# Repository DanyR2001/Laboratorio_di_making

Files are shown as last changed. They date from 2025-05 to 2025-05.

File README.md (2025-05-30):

# 🌀 Deumidificatore Smart DIY

Un deumidificatore intelligente basato su cella Peltier, controllabile via WiFi e Telegram, progettato per essere economico, modulare e open-source.

## 🚀 Panoramica
Progetto nato per risolvere problemi di umidità elevata (>80%) in ambienti domestici, offrendo un'alternativa economica e smart ai deumidificatori commerciali. Combina una cella Peltier con sensori di temperatura/umidità e controllo remoto in un case stampabile in 3D.

## 🔍 Caratteristiche Principali
- **Economico**: Costo totale ~50€ (vs 150-400€ modelli smart)
- **Smart Control**: Interfaccia web locale + Bot Telegram
- **Modulare**: Case stampabile in 3D con design modulare
- **Sostenibile**: Riutilizzo componenti da hardware dismesso
- **Monitoraggio**: Sensori temperatura/umidità in tempo reale
- **Silenzioso**: 37-52 dBA (a seconda della modalità)

## 📦 Componenti Richiesti
| Componente | Quantità | Prezzo Amazon | Prezzo AliExpress |
|---|---|---|---|
| ESP32 | 1 | €6,50 | €2,59 |
| Sensore AHT25 | 2 | €7,99 | €3,64 |
| Modulo Relè | 1 | €1,52 | €2,89 |
| Level Shifter 3.3V-5V | 1 | €1,40 | €0,11 |
| Multiplexer I2C | 1 | €1,60 | €0,42 |
| Alimentatore 12V 5A | 1 | €14,98 | €7,39 |
| DC-DC Step-down | 1 | €2,80 | €1,27 |
| Cella Peltier TEC1-12706| 1 | €4,50 | €2,06 |
| **Totale** | | **€41,29** | **€20,37** |

### 🛠️ Hardware Aggiuntivo
- Scheda Madre AM2 (ASROCK N68-S) per dissipatori: ~€25 su eBay
- Filamento PLA per stampa 3D

## ⚙️ Specifiche Tecniche
| Caratteristica | Valore |
|---|---|
| Capacità deumidificazione  | 0,3-0,4 L/giorno |
| Potenza refrigerante | ~10W |
| Consumo energetico | 24-30W (2,0-2,5A @12V)|
| Temperatura lato freddo | 8-18°C |
| Rumorosità | 37-52 dBA |
| Controllo umidità | 55-65% RH |
| Connettività | WiFi + Telegram Bot |

## 📂 Struttura del Progetto
Laboratorio_di_making/ <br />
├── Stl/           # File 3D per la stampa <br />
│   ├── Part 1.stl <br />
│   ├── Part 2.stl <br />
│   ├── Part 3.stl <br />
│   └── Part 4.stl <br />
├── Codice/        # Codice sorgente <br />
│   └── Main/ <br />
│       ├── main.ino <br />
│       └── exampleConfig.h <br />
├── Data/                # Dati ambientali campionati dai test <br />
│   ├── Umidità/ <br />  # Dati e codice per il test dell'umidità
│   └── Rumore/ <br />   # Dati fonometrice
├── Circuito/            # Schemi elettrici <br />
├── Documentazione/      # Relazione progetto <br />
└── README.md<br />
## ⚡ Setup e Installazione
### 1. Preparazione Hardware
- Stampa 3D: Stampa tutti i componenti del case usando PLA/PETG
- Assemblaggio: Monta i dissipatori dalla scheda madre AM2 sulla cella Peltier
- Cablaggio: Segui lo schema elettrico fornito
- Montaggio: Assembla tutti i componenti nel case stampato

### 2. Setup Software
1. Installa Arduino IDE e le librerie necessarie
2. Carica il firmware sull'ESP32

### 3. Configurazione Telegram BotCerca @BotFather su Telegram
1. Crea un nuovo bot con /newbot
2. Ottieni token e chat ID
3. Inserisci i dati in config.h

### 4. Accesso Web Interface 
- URL locale: http://esp32.local/
- API sensori: http://esp32.local/localSensors

## 📊 Prestazioni e Test
### Test di Collaudo
- Riduzione umidità: ~10% in 10 ore
- Rimozione vapore: ~150ml/50m³
- Temperatura operativa: Lato freddo 8-18°C, lato caldo ~50°C

### 🔈 Profilo Acustico

| Modalità | Livello Sonoro  |
|---|---|
| Sleep | 37,7 dBA |
| Min | 40 dBA |
| Med | 43 dBA |
| Max | 52 dBA |	
	
### ⚡ Efficienza Energetica
- Punto ottimale: 2,0-2,5A @ 12V
- COP: 0,7-0,8 nella zona ottimale
- Potenza frigorifera: 7-12W

## 🖥️ Utilizzo
### Web Interface
- Controllo ON/OFF del deumidificatore
- Monitoraggio temperature lato caldo/freddo
- Regolazione velocità ventola
- Visualizzazione dati sensori

### 🤖 Telegram Bot
- Stessi controlli dell'interfaccia web
- Controllo accesso tramite ID Telegram

## 🛠️ Personalizzazione
### Hardware
- Dissipatori maggiori per prestazioni superiori
- Doppia cella Peltier (configurazione cascata/parallela)
- Sistema di drenaggio per uso continuo

## Software
- Logging su SD per storico dati
- Integrazione cloud (dashboard online)
- App mobile dedicata
- Algoritmi ML per ottimizzazione automatica

## 🚀 Sviluppi Futuri
- Dashboard avanzata con grafici storici
- Integrazione domotica (Home Assistant, Alexa)
- AI optimization per cicli automatici
- App mobile nativa
- Cloud storage per i dati
- Notifiche push personalizzate

## 🤝 Contribuire
Contributi benvenuti! Processo suggerito:
1. Fork del repository
2. Crea un branch per la tua feature (git checkout -b feature/AmazingFeature)
3. Commit delle modifiche (git commit -m 'Add some AmazingFeature')
4. Push sul branch (git push origin feature/AmazingFeature)
5. Apri una Pull Request

### Aree di contributo
- Bug fix e ottimizzazioni
- Nuove funzionalità
- Miglioramenti documentazione
- Modifiche design case
- Test in condizioni diverse

## 📜 Licenza
Distribuito con licenza MIT. Vedi LICENSE per dettagli.

## ❓ Supporto
- Issues: Usa la sezione Issues di GitHub
- Discussioni: Partecipa alle Discussions
- Contatto diretto: [danielerusso_@hotmail.it]

## Disclaimer
Questo progetto è fornito "as-is" per scopi educativi e di prototipazione. Utilizzare con cautela rispettando le norme di sicurezza elettrica.

# ⭐ Se questo progetto ti è stato utile, lascia una stella su GitHub!

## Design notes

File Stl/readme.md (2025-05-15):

# Printer Setting
Ho stampato questi modelli con delle impostazioni classiche, utilizzando del PETG
- Infill 15%
- Altezza layer: 0.2 mm
- temperatura di stampa 240°

Nei file:
- Part 2
- Part 3
Sono necessari dei supporti per la stampa

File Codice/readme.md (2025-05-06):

# Some info
Qui è riportato un file exampleConfig.h che dovrai compilare per far funzionare l'esp32!!

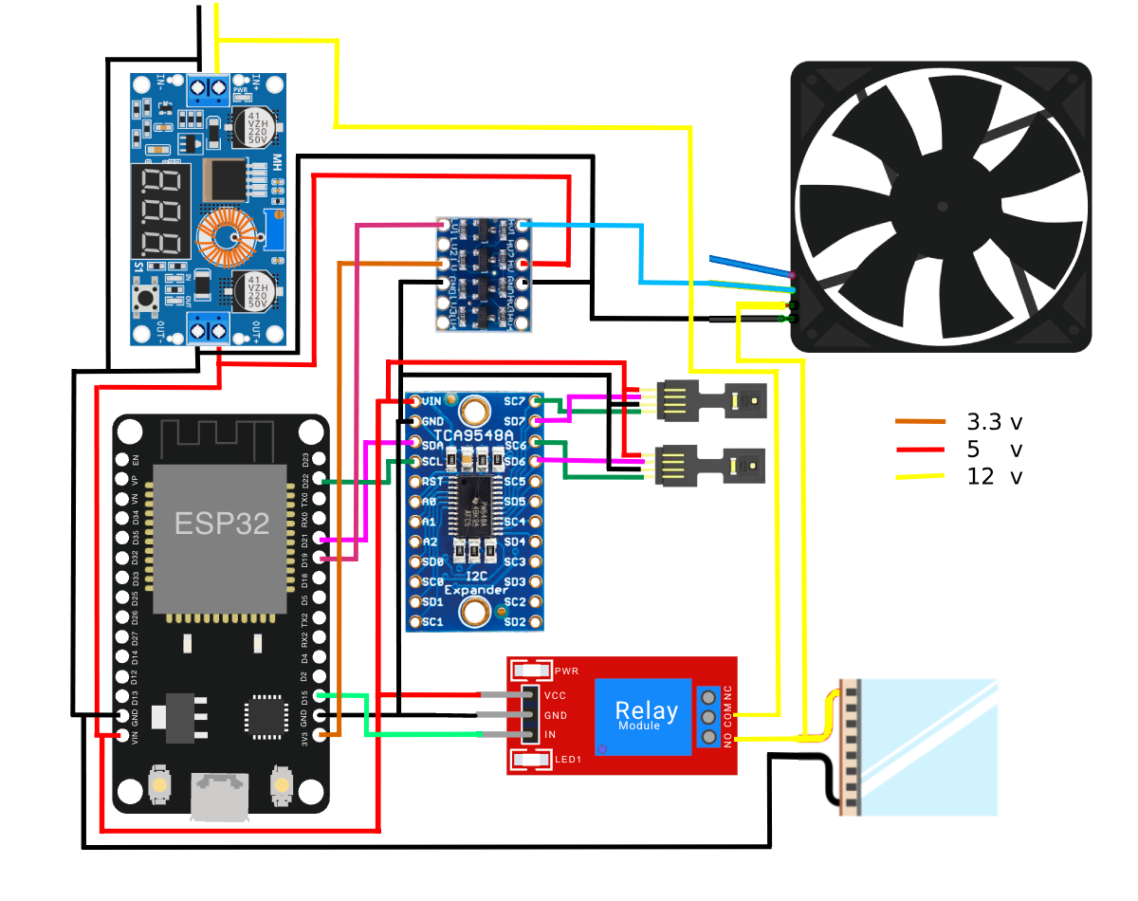
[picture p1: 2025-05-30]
Circuito/schema collegamenti.png

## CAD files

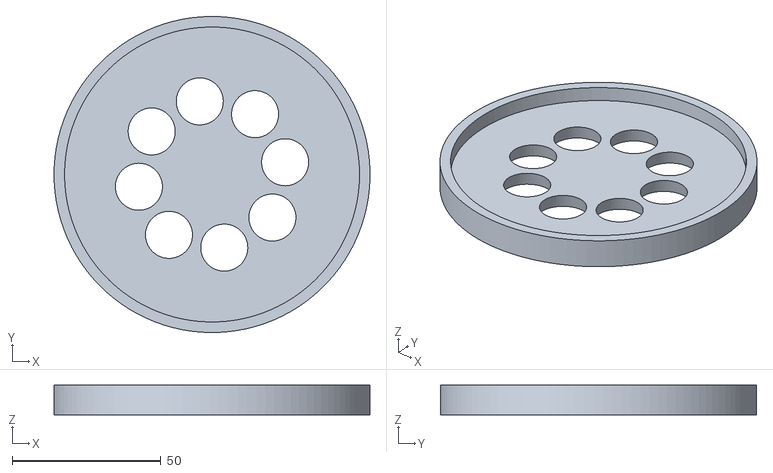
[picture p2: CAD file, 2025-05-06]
Stl/Part 1.stl
106.1 x 106.1 x 10.0

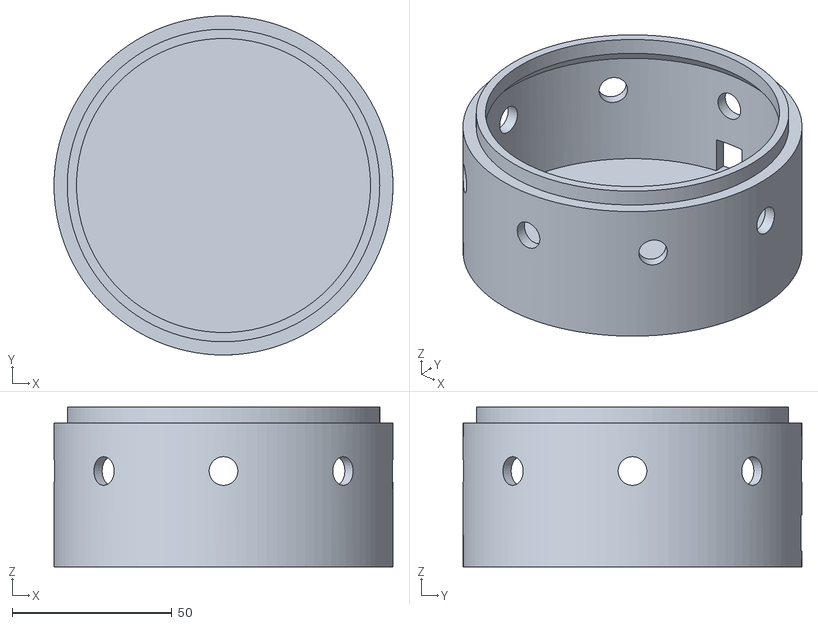
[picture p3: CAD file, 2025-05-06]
Stl/Part 4.stl
106.1 x 106.1 x 50.0

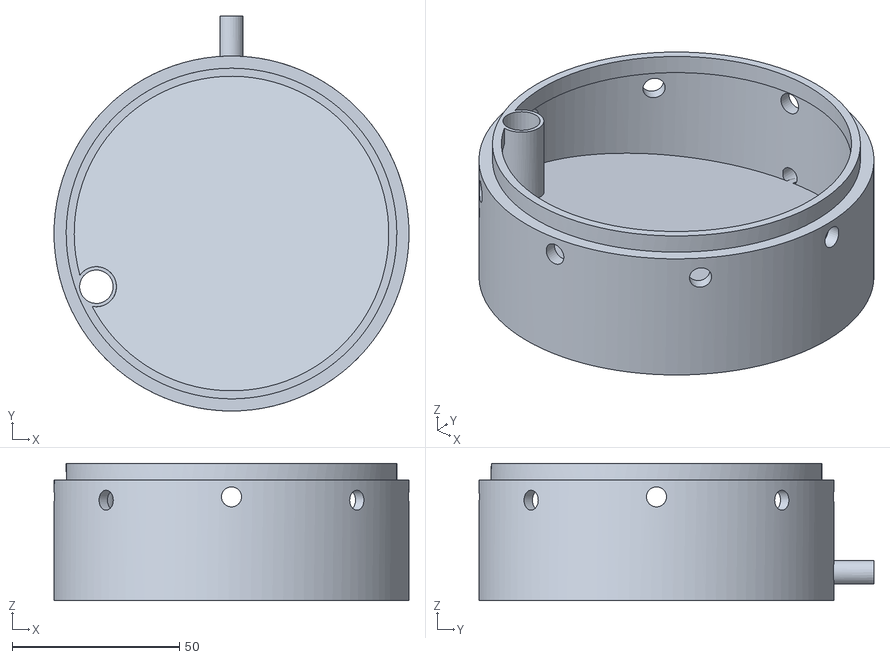
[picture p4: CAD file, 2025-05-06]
Stl/Part 3.stl
106.1 x 118.0 x 41.0

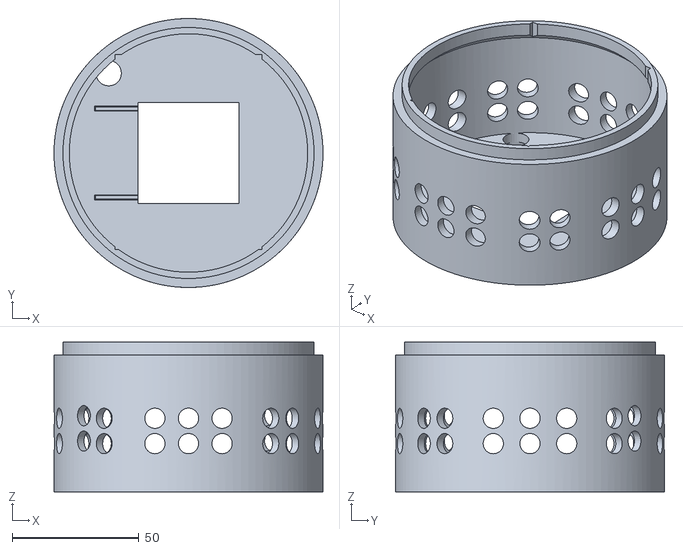
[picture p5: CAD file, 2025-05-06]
Stl/Part 2.stl
106.1 x 106.1 x 59.0

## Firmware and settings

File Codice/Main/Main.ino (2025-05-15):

#include <HTTPClient.h>
#include <WiFi.h>
#include <WebServer.h>
#include <AHTxx.h>
#include <Wire.h>
#include <WiFiClientSecure.h>
#include <UniversalTelegramBot.h>
#include <esp32-hal-ledc.h>
#include "config.h"
#include <time.h>
#include <ESPmDNS.h>

// NTP per SSL
const char* ntpServer = "pool.ntp.org";
const long gmtOffset_sec = 3600;        // Europa/Rome
const int daylightOffset_sec = 3600;    // ora legale
const unsigned long ntpTimeout = 10000; // 10 secondi timeout NTP


// Pin I2C e sensore
#define I2C_SDA       21
#define I2C_SCL       22
#define SENSOR_ADDR   0x38

// Pin relè
#define RELAY_PIN     16

// PWM ventola/LED
#define FAN_PWM_PIN        17
#define FAN_PWM_FREQ       25000
#define FAN_PWM_RESOLUTION 8

// Multiplexer TCA9548A
#define MUX_ADDR 0x70

// Definizione della tastiera inline
String keyboardJson = "[[{\"text\":\"SLEEP\",\"callback_data\":\"fan_47\"},"
                      "{\"text\":\"MIN\",\"callback_data\":\"fan_100\"}],"
                      "[{\"text\":\"MED\",\"callback_data\":\"fan_170\"},"
                      "{\"text\":\"MAX\",\"callback_data\":\"fan_255\"}]]";

WebServer server(80);
WiFiClientSecure secureClient;
UniversalTelegramBot bot(botToken, secureClient);
AHTxx aht25(SENSOR_ADDR, AHT2x_SENSOR);

float temp1=0, hum1=0;
float temp2=0, hum2=0;
bool relayState=false;
int fanSpeed=0;

// Controllo accesso Telegram
bool isAuthorized(const String& chat_id) {
  for (int i = 0; i < NUM_AUTHORIZED_USERS; ++i) {
    if (chat_id == String(AUTHORIZED_USERS[i])) return true;
  }
  return false;
}

// Selettore canale MUX
void selectMUXChannel(uint8_t channel) {
  Wire.beginTransmission(MUX_ADDR);
  Wire.write(1 << channel);
  Wire.endTransmission();
  delay(100);
}

bool readSensor1() {
  selectMUXChannel(1);
  if (!aht25.begin(I2C_SDA, I2C_SCL, 100000)) return false;
  temp1 = aht25.readTemperature();
  hum1  = aht25.readHumidity();
  Serial.printf("Sens1: %.1f°C, %.1f%%\n", temp1, hum1);
  return true;
}
bool readSensor2() {
  selectMUXChannel(2);
  if (!aht25.begin(I2C_SDA, I2C_SCL, 100000)) return false;
  temp2 = aht25.readTemperature();
  hum2  = aht25.readHumidity();
  Serial.printf("Sens2: %.1f°C, %.1f%%\n", temp2, hum2);
  return true;
}

void setFanSpeed(int speed) {
  fanSpeed = constrain(speed, 0, 255);
  ledcWrite(FAN_PWM_PIN, fanSpeed);
}

String webpage() {
  String page = R"rawliteral(
<!DOCTYPE html>
<html>
<head>
  <meta charset="utf-8">
  <title>ESP32 Dashboard</title>
  <meta name="viewport" content="width=device-width,initial-scale=1">
  <link href="https://cdn.jsdelivr.net/npm/bootstrap@5.3.3/dist/css/bootstrap.min.css" rel="stylesheet">
</head>
<body class="bg-light">
  <div class="container py-4">

    <h1 class="text-center mb-4">🌬️ Smart Climate Controller</h1>

    <!-- Riga principale -->
    <div class="row gx-4 gy-4 align-items-stretch">

      <!-- Colonna sinistra: DEUMIDIFICATORE (rowspan 2) -->
      <div class="col-md-3 d-flex">
        <div class="card shadow-sm flex-fill">
          <div class="card-body d-flex flex-column justify-content-center text-center">
            <h5 class="card-title">💧 Deumidificatore</h5>
            <button class="btn btn-success m-1" onclick="toggleRelay('on')">Accendi</button>
            <button class="btn btn-danger m-1" onclick="toggleRelay('off')">Spegni</button>
            <p class="mt-3 h5">Stato: <span id="relay">%R%</span></p>
        </div>
        </div>
      </div>

      <!-- Colonna centrale: 2 card impilate -->
      <div class="col-md-6">
        <div class="row gx-4 gy-4">

          <!-- Temperatura lato caldo -->
          <div class="col-12">
            <div class="card shadow-sm h-100">
              <div class="card-body">
                <h5 class="card-title">🔥 Temperatura lato caldo</h5>
                <p id="sensor2" class="display-5 mb-1">%S2%</p>
                <span id="hum2" class="badge bg-warning">Umidità: %H2%%</span>
              </div>
            </div>
          </div>

          <!-- Temperatura lato freddo -->
          <div class="col-12">
            <div class="card shadow-sm h-100">
              <div class="card-body">
                <h5 class="card-title">🌡️ Temperatura lato freddo</h5>
                <p id="sensor1" class="display-5 mb-1">%S1%</p>
                <span id="hum1" class="badge bg-info">Umidità: %H1%%</span>
              </div>
            </div>
          </div>

        </div>
      </div>

      <!-- Colonna destra: VENTOLA (rowspan 2) -->
      <div class="col-md-3 d-flex">
        <div class="card shadow-sm flex-fill">
          <div class="card-body d-flex flex-column justify-content-center text-center">
            <h5 class="card-title">🌀 Ventola</h5>
            <button class="btn btn-secondary m-1" onclick="setFan(47)">SLEEP</button>
            <button class="btn btn-primary m-1"   onclick="setFan(100)">MIN</button>
            <button class="btn btn-warning m-1"   onclick="setFan(170)">MED</button>
            <button class="btn btn-danger m-1"    onclick="setFan(255)">MAX</button>
            <p class="mt-3 h5">Velocità: <span id="fval">%F%</span></p>
          </div>
        </div>
      </div>

    </div>
  </div>

<script>
function toggleRelay(s) {
  fetch('/relay/' + s)
    .then(r => r.text())
    .then(d => { document.getElementById('relay').innerText = d; });
}

function setFan(v) {
  fetch('/fan?speed=' + v)
    .then(r => r.text())
    .then(_ => {
      document.getElementById('fval').innerText = v;
    });
}

function update() {
  fetch('/status')
    .then(r => r.json())
    .then(d => {
      document.getElementById('relay').innerText    = d.relay    ? 'Acceso' : 'Spento';
      document.getElementById('fval').innerText     = d.fanSpeed;
      document.getElementById('sensor2').innerText  = d.temp2.toFixed(1) + ' °C';
      document.getElementById('hum2').innerText     = 'Umidità: ' + d.hum2.toFixed(1) + '%';
      document.getElementById('sensor1').innerText  = d.temp1.toFixed(1) + ' °C';
      document.getElementById('hum1').innerText     = 'Umidità: ' + d.hum1.toFixed(1) + '%';
    });
}

// Primo refresh e poi ogni secondo
update();
setInterval(update, 2000);
</script>

</body>
</html>
)rawliteral";

  page.replace("%S1%", String(temp1,1) + " °C");
  page.replace("%H1%", String(hum1,1));
  page.replace("%S2%", String(temp2,1) + " °C");
  page.replace("%H2%", String(hum2,1));
  page.replace("%R%", relayState ? "Acceso" : "Spento");
  page.replace("%F%", String(fanSpeed));

  return page;
}

void handleRoot() { server.send(200, "text/html", webpage()); }
void handleRelayOn() { digitalWrite(RELAY_PIN, HIGH); relayState=true; server.send(200,"text/plain","Acceso"); }
void handleRelayOff(){ digitalWrite(RELAY_PIN, LOW); relayState=false; server.send(200,"text/plain","Spento"); }
void handleFan() { if(server.hasArg("speed")){ setFanSpeed(server.arg("speed").toInt()); server.send(200,"text/plain","OK"); } else server.send(400,"text/plain","Missing"); }
void handleLocalSensors() {
  // Leggi i due sensori locali
  if (!readSensor1() || !readSensor2()) {
    server.send(500, "text/plain", "Errore lettura sensori locali");
    return;
  }
  // Costruisci il JSON di risposta
  String resp = "{";
  resp += "\"temp1\":" + String(temp1,1) + ",";
  resp += "\"hum1\":"  + String(hum1,1)  + ",";
  resp += "\"temp2\":" + String(temp2,1) + ",";
  resp += "\"hum2\":"  + String(hum2,1);
  resp += "}";
  server.send(200, "application/json", resp);
}


void handleStatus(){
  String j = "{";
  j += "\"temp1\":" + String(temp1,1) + ",";
  j += "\"hum1\":" + String(hum1,1) + ",";
  j += "\"temp2\":" + String(temp2,1) + ",";
  j += "\"hum2\":" + String(hum2,1) + ",";
  j += "\"relay\":";
  j += relayState ? "true" : "false";
  j += ",";
  j += "\"fanSpeed\":" + String(fanSpeed);
  j += "}";
  server.send(200, "application/json", j);
}

void reconnectWiFi() {
  if (WiFi.status() == WL_CONNECTED) return;
  Serial.println("Riconnessione WiFi...");
  WiFi.disconnect();
  WiFi.reconnect();
  unsigned long start = millis();
  while (WiFi.status() != WL_CONNECTED && millis() - start < 15000) {
    delay(500);
    Serial.print(".");
  }
  if (WiFi.status() == WL_CONNECTED) {
    Serial.println("\nWiFi riconnesso");
    // Riconfigura client sicuro dopo la riconnessione
    secureClient.stop(); // Chiude la connessione precedente
    secureClient.setCACert(TELEGRAM_CERTIFICATE_ROOT); // Imposta il certificato
    configTime(gmtOffset_sec, daylightOffset_sec, ntpServer); // Ri-sincronizza NTP
  } else {
    Serial.println("\nFallimento riconnessione WiFi!");
  }
}

bool syncNTP() {
  Serial.print("Sincronizzazione NTP");
  configTime(gmtOffset_sec, daylightOffset_sec, ntpServer);
  struct tm timeinfo;
  unsigned long start = millis();
  while (millis() - start < ntpTimeout) {
    if (getLocalTime(&timeinfo, 5000)) { // Timeout 5s
      Serial.println(" OK");
      return true;
    }
    Serial.print(".");
    delay(500);
  }
  Serial.println(" Fallito!");
  return false;
}

void setup() {
  Serial.begin(115200);

  WiFi.begin(ssid, password);
  while (WiFi.status()!=WL_CONNECTED) delay(500);
  Serial.printf("IP: %s\n", WiFi.localIP().toString().c_str());

  if (MDNS.begin("esp32")) {
    Serial.println("mDNS avviato: esp32.local");
    MDNS.addService("http", "tcp", 80); // Registra il servizio HTTP
  } else {
    Serial.println("Errore nell'avvio di mDNS");
  }


  if (!syncNTP()) {
    Serial.println("Avvio senza tempo sincronizzato. SSL potrebbe non funzionare!");
  }

  pinMode(RELAY_PIN, OUTPUT); digitalWrite(RELAY_PIN, LOW);
  Wire.begin(I2C_SDA, I2C_SCL, 100000);
  pinMode(FAN_PWM_PIN, OUTPUT);
  ledcAttach(FAN_PWM_PIN, FAN_PWM_FREQ, FAN_PWM_RESOLUTION);
  setFanSpeed(0);

  server.on("/", handleRoot);
  server.on("/relay/on", handleRelayOn);
  server.on("/relay/off", handleRelayOff);
  server.on("/fan", handleFan);
  server.on("/status", handleStatus);
  server.on("/localSensors", HTTP_GET, handleLocalSensors);
  server.begin();
  secureClient.setCACert(TELEGRAM_CERTIFICATE_ROOT);
}

void loop() {
  reconnectWiFi();

  server.handleClient();
  static unsigned long lastRun = 0;
  static unsigned long lastSensorRead = 0;

  if(millis() - lastSensorRead > 1500) {
    readSensor1();
    readSensor2();
    lastSensorRead = millis();
  }

  if (millis() - lastRun > 1000) {
    int n = bot.getUpdates(bot.last_message_received + 1);
    while (n) {
      for (int i = 0; i < n; ++i) {
        String cid = String(bot.messages[i].chat_id);
        String txt = bot.messages[i].text;
        String uname = bot.messages[i].from_name;

        if (!isAuthorized(cid)) {
          bot.sendMessage(cid, "🚫 *Accesso negato.*\n"
                               "Il tuo ID non è autorizzato a utilizzare questo bot.\n"
                               "Contatta l'amministratore per richiedere l'accesso.",
                               "Markdown");
          continue;
        }

        if (bot.messages[i].type == "callback_query") {
        String callbackData = bot.messages[i].text;
        if (callbackData.startsWith("fan_")) {
          int speed = callbackData.substring(4).toInt();
          setFanSpeed(speed);
          bot.sendMessage(cid, "✅ Velocità ventola impostata a " + String(speed), "");
        }
      } else if (txt == "/fan") {
        bot.sendMessageWithInlineKeyboard(cid,
          "🌀 Seleziona la velocità della ventola:",
          "", keyboardJson);
      }else if (txt == "/start") {
          String msg = "👋 *Benvenuto " + uname + "!*\n"
                       "Questo bot controlla un deumidificatore DIY basato su ESP32 con sensori AHT25, relè e ventola.\n\n"
                       "💡 Usa /help per vedere tutti i comandi disponibili.";
          bot.sendMessage(cid, msg, "Markdown");
        } else if (txt == "/help") {
          String msg = "📋 *Comandi disponibili:*\n"
                       "/sensors – Mostra valori dei sensori\n"
                       "/turnon – Accende il deumidificatore\n"
                       "/turnoff – Spegne il deumidificatore\n"
                       "/fan – Imposta la velocità della ventola\n"
                       "/status – Stato generale (sensori, stato, ventola)\n"
                       "/help – Mostra questo messaggio\n"
                       "/start – Messaggio di benvenuto";
          bot.sendMessage(cid, msg, "Markdown");
        } else if (txt == "/sensors") {
          String msg = String("🌡️ *Sensori:*\n") +
                       "Sensore lato freddo ❄️: " + String(temp1,1) + "°C, " + String(hum1,1) + "%\n" +
                       "Sensore lato caldo 🔥: " + String(temp2,1) + "°C, " + String(hum2,1) + "%";
          bot.sendMessage(cid, msg, "Markdown");
        } else if (txt == "/turnon") {
          digitalWrite(RELAY_PIN, HIGH); relayState = true;
          bot.sendMessage(cid, "🔌 Deumidificatore acceso", "");
        } else if (txt == "/turnoff") {
          digitalWrite(RELAY_PIN, LOW); relayState = false;
          bot.sendMessage(cid, "🔌 Deumidificatore spento", "");
        } else if (txt.startsWith("/fan_speed")) {
          int sp = txt.substring(11).toInt(); setFanSpeed(sp);
          bot.sendMessage(cid, "🌀 Velocità ventola impostata a " + String(fanSpeed), "");
        } else if (txt == "/status") {
          String msg = String("📊 *Stato sistema:*\n") +
                       "Sensore lato freddo ❄️: " + String(temp1,1) + "°C, " + String(hum1,1) + "%\n" +
                       "Sensore lato caldo 🔥: " + String(temp2,1) + "°C, " + String(hum2,1) + "%\n" +
                       "Stato Deumificatore: " + (relayState ? "On" : "Off") + "\n" +
                       "Ventola: " + String(relayState ? String(fanSpeed) : "Off");
          bot.sendMessage(cid, msg, "Markdown");
        } else {
          bot.sendMessage(cid, "❓ Comando non riconosciuto. Usa /help per la lista dei comandi.");
        }
      }
      lastRun = millis();
      n = bot.getUpdates(bot.last_message_received + 1);
    }
  }
}

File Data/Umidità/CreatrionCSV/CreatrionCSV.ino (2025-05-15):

#include <WiFi.h>
#include <WebServer.h>
#include <HTTPClient.h>
#include <ArduinoJson.h>
#include <SPIFFS.h>
#include <Ticker.h>
#include "DHT.h"
#include <time.h>

// ————— CONFIGURAZIONE —————
const char* ssid       = "YourSSID";
const char* password   = "YourPassword";
const char* filePath   = "/data.csv";

// Debug: se true esegue solo la prima misurazione
const bool debugMode   = false;

// Intervallo e numero max di campionamenti
const uint32_t intervalMs = 15UL * 60UL * 1000UL;  // 30 minuti
const uint8_t  maxSamples = 9 * 4;                 // 9h / 0.5h = 18 campionamenti

Ticker    sensorTicker;
uint8_t   sampleCount = 0;

WebServer server(80);

// ————— DHT11 LOCALE —————
#define LOCAL_DHT_PIN  4
#define LOCAL_DHT_TYPE DHT11
DHT dht(LOCAL_DHT_PIN, LOCAL_DHT_TYPE);

// Variabili sensori remoti e locali
float temp1 = 0.0, hum1 = 0.0, temp2 = 0.0, hum2 = 0.0;
float localTemp = 0.0, localHum = 0.0;

// ————— SETUP SPIFFS —————
void initSPIFFS() {
  if (!SPIFFS.begin(true)) {
    Serial.println("Errore montaggio SPIFFS, provo a formattare...");
    if (SPIFFS.format()) {
      Serial.println("Formattazione OK, rimonto SPIFFS...");
      if (!SPIFFS.begin(true)) {
        Serial.println("Errore dopo format");
        return;
      }
    } else {
      Serial.println("Formattazione fallita");
      return;
    }
  }
  Serial.println("SPIFFS montato");

  if (!SPIFFS.exists(filePath)) {
    File f = SPIFFS.open(filePath, FILE_WRITE);
    if (f) {
      f.println("timestamp,temp1,hum1,temp2,hum2,localTemp,localHum");
      f.close();
      Serial.println("CSV inizializzato");
    } else {
      Serial.println("Errore creazione CSV");
    }
  } else {
    Serial.println("CSV esistente trovato");
  }
}

void appendCSV(const String &line) {
  File f = SPIFFS.open(filePath, FILE_APPEND);
  if (!f) {
    Serial.println("Errore apertura CSV per append");
    return;
  }
  f.println(line);
  f.close();
}

// ————— GET REMOTE SENSORS —————
// Chiamata HTTP a ESP B per leggere /localSensors
bool getRemoteSensors(float &outT1, float &outH1, float &outT2, float &outH2) {
  HTTPClient http;
  http.begin("http://esp32.local/localSensors");
  int code = http.GET();
  if (code != HTTP_CODE_OK) {
    Serial.printf("Errore GET remota: %d\n", code);
    http.end();
    return false;
  }
  String payload = http.getString();
  http.end();

  DynamicJsonDocument doc(256);
  auto err = deserializeJson(doc, payload);
  if (err) {
    Serial.print("JSON parse error: ");
    Serial.println(err.c_str());
    return false;
  }

  outT1 = doc["temp1"].as<float>();
  outH1 = doc["hum1"].as<float>();
  outT2 = doc["temp2"].as<float>();
  outH2 = doc["hum2"].as<float>();
  return true;
}

// ————— SAMPLING FUNCTION —————
void startSampling() {
  sampleCount++;
  Serial.printf("Campione %d di %d\n", sampleCount, maxSamples);

  // 1) Lettura DHT locale
  localHum  = dht.readHumidity();
  localTemp = dht.readTemperature();
  if (isnan(localHum) || isnan(localTemp)) {
    Serial.println("Errore lettura DHT locale");
    localHum = localTemp = 0.0;
  } else {
    Serial.printf("Locale: T=%.1f°C H=%.1f%%\n", localTemp, localHum);
  }

  // 2) Lettura sensori remoti da ESP B
  if (!getRemoteSensors(temp1, hum1, temp2, hum2)) {
    Serial.println("Errore lettura remota, zero valori");
    temp1 = hum1 = temp2 = hum2 = 0.0;
  } else {
    Serial.printf("Remoto: T1=%.1f H1=%.1f | T2=%.1f H2=%.1f\n",
                  temp1, hum1, temp2, hum2);
  }

  // 3) Costruisci linea CSV e salva
  time_t now = time(nullptr);
  String line = String(now) + "," +
                String(temp1,1) + "," + String(hum1,1) + "," +
                String(temp2,1) + "," + String(hum2,1) + "," +
                String(localTemp,1) + "," + String(localHum,1);
  appendCSV(line);
  Serial.println("Salvato: " + line);

  // 4) Ferma ticker se terminato
  if (debugMode || sampleCount >= maxSamples) {
    sensorTicker.detach();
    Serial.println("Campionamento completato");
  }
}

// ————— SETUP & LOOP —————
void setup() {
  Serial.begin(115200);
  delay(500);
  Serial.println("\n--- Avvio sistema sensori ---");

  dht.begin();
  initSPIFFS();

  // Connetti WiFi
  WiFi.begin(ssid, password);
  Serial.print("Connettendo a WiFi");
  unsigned long start = millis();
  while (WiFi.status() != WL_CONNECTED && millis() - start < 20000) {
    delay(250);
    Serial.print(".");
  }
  if (WiFi.status() != WL_CONNECTED) {
    Serial.println("\nImpossibile connettersi al WiFi");
    return;
  }
  Serial.println("\nWiFi connesso, IP: " + WiFi.localIP().toString());

  server.on("/download", HTTP_GET, [](){
  File file = SPIFFS.open(filePath, "r");
  if (!file) {
    server.send(404, "text/plain", "File non trovato");
    return;
  }
  server.streamFile(file, "text/csv");
  file.close();
  });
  server.begin();
  Serial.println("Server HTTP avviato");

  // Sincronizza orologio via NTP
  configTime(1*3600, 1*3600, "pool.ntp.org");
  Serial.println("Sincronizzazione NTP in corso...");
  start = millis();
  while (time(nullptr) < 24*3600 && millis() - start < 10000) {
    delay(100);
  }
  Serial.println("Orologio pronto: " + String(time(nullptr)));

  // Primo campionamento e avvio ticker
  startSampling();
  if (!debugMode) {
    sensorTicker.attach_ms(intervalMs, startSampling);
    Serial.printf("Ticker avviato (%lums)\n", intervalMs);
  }
}

void loop() {
  server.handleClient();
  // Comandi via seriale
  if (Serial.available()) {
    String cmd = Serial.readStringUntil('\n');
    cmd.trim();
    if (cmd == "read") {
      // Stampa contenuto CSV
      if (SPIFFS.exists(filePath)) {
        File f = SPIFFS.open(filePath, FILE_READ);
        while (f.available()) {
          Serial.println(f.readStringUntil('\n'));
        }
        f.close();
      } else {
        Serial.println("Nessun CSV trovato");
      }
    }
    else if (cmd == "sample") {
      startSampling();
    }
    else if (cmd == "format") {
      SPIFFS.format();
      initSPIFFS();
    }
    else if (cmd == "reset") {
      ESP.restart();
    }
    else if (cmd == "help") {
      Serial.println("Comandi: read, sample, format, reset, help");
    }
  }
  delay(50);
}

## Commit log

2025-05-06 First commit
    Aggiunta dei modelli stl, del codice e dello schema elettrico
    [Part 1.stl, Part 2.stl, Part 3.stl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]
2025-05-15 Aggiunta programma per leggere temperatura e umidità + aggiornamento del main program
2025-05-30 Aggiunta rilevazioni rumore
    [rawData.csv]
